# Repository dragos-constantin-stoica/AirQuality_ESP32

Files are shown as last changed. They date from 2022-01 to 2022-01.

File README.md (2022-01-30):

# AirQuality monitoring with ESP32
Air Quality, Temperature, Humidity IoT platform with ESP32

## Introduction

This is a prototype for a station that is monitoring the following parameters:
- Temperature in °C, if you use F please change accordingly in the code
- Humidity in %
- Air Quality in ppm. The sensor measures: CO, Alcohol, CO2, Tolueno, NH4, and Acetona

The device will store the measured data on SD card and is programmed to send data to uBeac, as IoT data collection platform.

The main microcontroller is ESP32 (WROOM-32) and it has the follwing peripherals:
- MQ135 air quality sensor
- DHT22 temperature and humidity sensor
- microSD card reader
- DS3231 RTC clock
- SSD1306 OLED display

Most of the components were purchased from [AZ-Delivery](https://www.az-delivery.de/en) and [Amazon](https://www.amazon.de/)

## What can you find in this repository?

### AQ

Contains the Arduino code. I used Arduino v1.8.19 desktop on a MacBook.
Extra repository configuraiton:
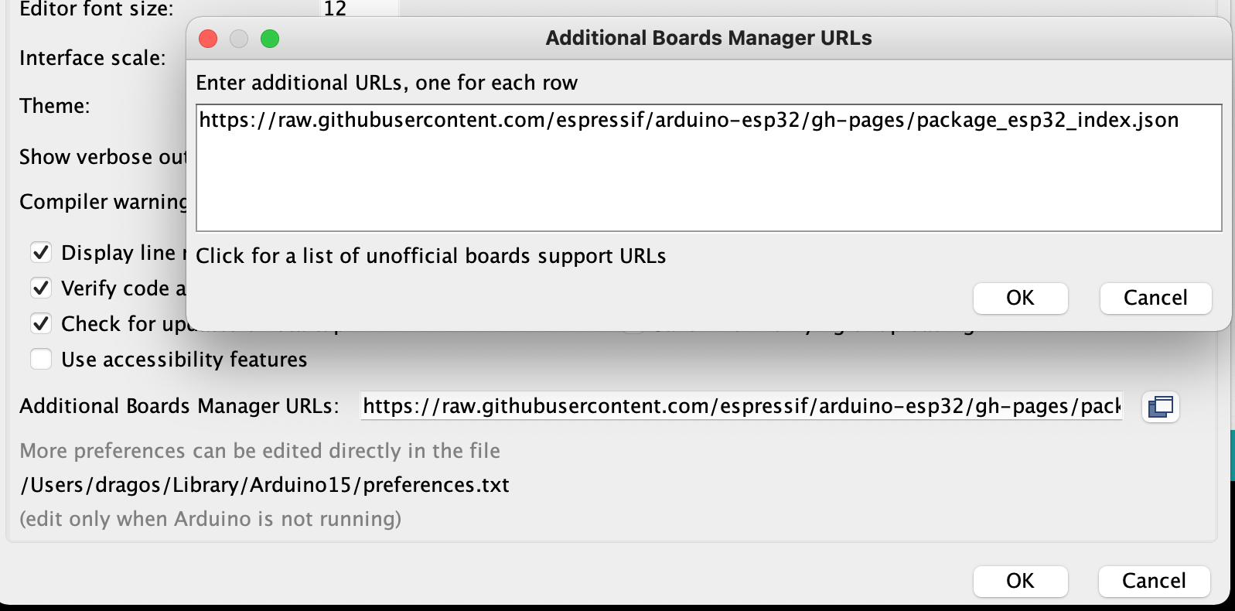
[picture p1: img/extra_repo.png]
Add extra repositories

This is the official repository provided by Expressif - the manufacturer of the ESP32 chipset.

List of libraries:
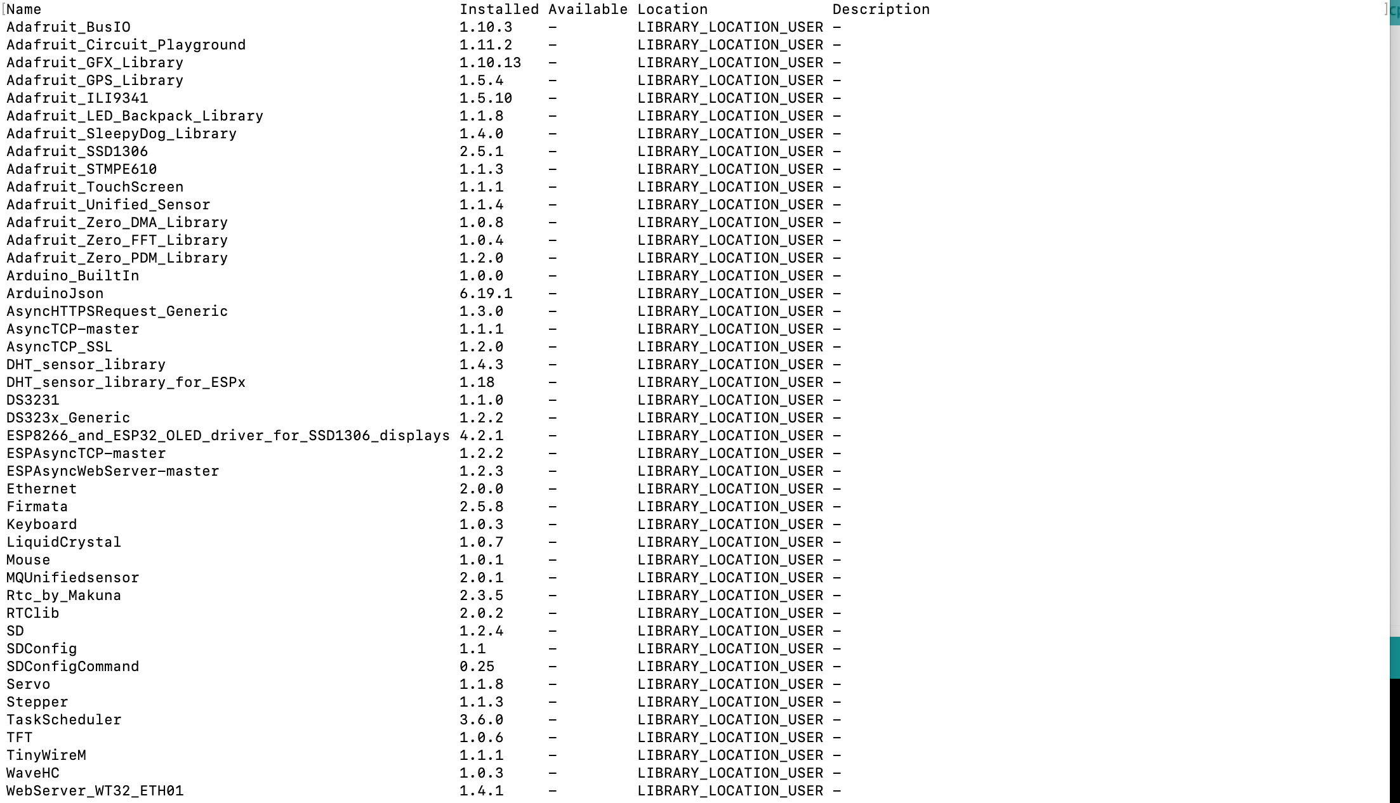
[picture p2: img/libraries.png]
Extra libraries


Some libraries were downloaded and installed manually.

Board configuration:
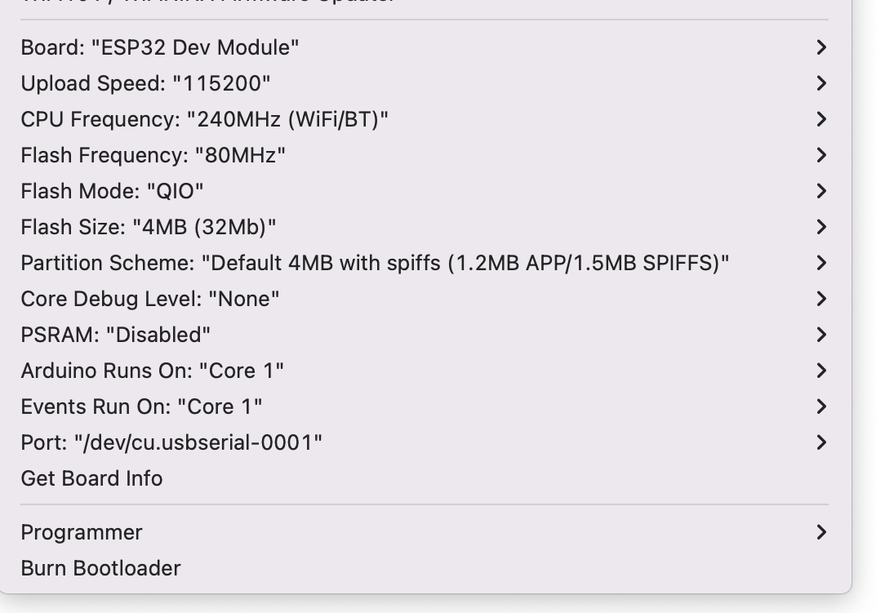
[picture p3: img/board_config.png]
Board configuration


Build the code and upload it into device via USB cable. You need USB to microUSB cable.

### Fritzing

The Fritzing schema. You can find the electronic schema and the breadboard prototype. The PCB was generated by Fritzing but not used for the actual implementation and soldering.

I used an one hole PCB card 7x9 cm for the final soldering of components.

### SD_card

This folder must be copied onto the SD card before you start the Air Quality monitoring station. You have an **index.html** file that will be served by the local web server. The web server is accessible via the IP displayed on OLED.  
The system log file is also stored on the SD card - see file **airquality.log**. This file can be accessed via the local web sever.  

The most important file is the **aq.cfg** this contains the configuration that will initialize the system. You **must** provide an **WiFi SSID** so that the device can connect and start monitoring. Additionally you can send the data to [uBeac](https://ubeac.io). Please follow the instructions on uBeac site in order to create the propper configuration and include it in **aq.cfg**.

## How does it work?
You need to build the physical device before starting. You can either use a breadboard with wires or solder the components on a PCB. I do recommend to start with breadboard first. Use fritzing schema to build the device.

Step 0.   
Format the SD card as fat. I used a 16GB microSD card. The speed of the card is not important.

Step 1.  
Edit aq.cfg file accordingly before copying. Copy the files from forder SD_card to your microSD card. 

Step 2.  
Copile and upload the AQ.ino on ESP32 board.

The device must boot and show a message on OLED that looks like:
```
WiFi SSID [OK]
uBeac setup [OK]
DHT22 [OK]
MQ135 [OK]
AQ monitoring [OK]
IP: 192.168.178.58
```

You can use the serial monitor from Ardunio to see the verbouse log. This is an excellent tool for debugging and troubleshooting.

:four_leaf_clover: Wish you best of luck! :four_leaf_clover:

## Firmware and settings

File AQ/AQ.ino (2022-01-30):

//
//
//  Air Quality (AQ)
//
//  This is a prototype for air quality monitoring system.
//  It runs on an ESP32 platform with
//  - MQ135 sensor for gas
//  - DHT22 sensor for temperature and humidity
//
//  @author: Dragoş STOICA
//  @email: dragos.constantin.stoica@outlook.com
//  @date: 07.09.2020
//

/****************************************
   Include Libraries
 ****************************************/
#include "utilsSD.h"
#include "utilsCfg.h"
#include "utilsTime.h"
#include "utilsOLED.h"
#include "utilsSensor.h"
#include "utilsWiFi.h"


extern bool IS_WIFI;
//-------------------------------------------------------------------------
// Prepare the device:
// - sync time
// - initialize sensors
// - start local webserver
//-------------------------------------------------------------------------
void setup() {
  //init and get the time
  setenv("TZ", "  CET-1CEST,M3.5.0,M10.5.0/3", 1);
  // You must include '0' after first designator e.g. GMT0GMT-1, ',1' is true or ON

  Serial.begin(115200);
  Serial.println("'Oo._");
  Serial.println("*** Program Start : ESP32 with MQ135 and DHT22");
  /*
     The main init sequence

     0. Init SD card
        - read WiFi config from aq.cfg
        - read IoT config form aq.cfg
        - write log file airquality.log
     1. Init OLED
     2. Init Sensors
     3. Init WiFi
        - init Webserver if WiFi config present
        - init IoT send data if IoT config present

     Deal with RTC init
      > initialize RTC first
      > consider that RTC is OK and use it from the beggining
      > when WiFi connection is established do synchronize the RTC with web time server
  */
  init_RTC();
  sd_init();
  cfg_init();
  oled_init();

  // Initialize temperature and air quality sensors
  initDHT22();
  oled_addline("DHT22 [OK]");
  initMQ135();
  oled_addline("MQ135 [OK]");

  if (IS_WIFI) {
    oled_addline("AQ monitoring [OK]");
    wifi_init();
  } else {
    oled_addline("AQ monitoring !NOK!");
    oled_addline(">... SYSTEM HALT!");
    oled_display();
  }
}

void loop() {
  if (IS_WIFI) {
    wifi_run();
  }
}

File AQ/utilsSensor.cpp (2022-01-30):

// Include the necessary libraries
#include "utilsSensor.h"
#include "utilsTime.h"
#include "utilsSD.h"
#include <Arduino.h>


DHT_Unified dht(DHTPIN, DHTTYPE);
MQUnifiedsensor MQ135(Board, Voltage_Resolution, ADC_Bit_Resolution, Pin, Type);
SENSOR_DATA last_reading = { 0.0, 0.0, 0.0, 0.0, 0.0, 0.0, 0.0, 0.0 };


/* Init sensors */
void initDHT22() {
  // Initialize device.
  dht.begin();
  Serial.println(F("DHT22 Unified Sensor"));
  // Print temperature sensor details.
  sensor_t sensor;
  dht.temperature().getSensor(&sensor);
  Serial.println(F("------------------------------------"));
  Serial.println(F("Temperature Sensor"));
  Serial.print  (F("Sensor Type: ")); Serial.println(sensor.name);
  Serial.print  (F("Driver Ver:  ")); Serial.println(sensor.version);
  Serial.print  (F("Unique ID:   ")); Serial.println(sensor.sensor_id);
  Serial.print  (F("Max Value:   ")); Serial.print(sensor.max_value); Serial.println(F("°C"));
  Serial.print  (F("Min Value:   ")); Serial.print(sensor.min_value); Serial.println(F("°C"));
  Serial.print  (F("Resolution:  ")); Serial.print(sensor.resolution); Serial.println(F("°C"));
  Serial.println(F("------------------------------------"));
  // Print humidity sensor details.
  dht.humidity().getSensor(&sensor);
  Serial.println(F("Humidity Sensor"));
  Serial.print  (F("Sensor Type: ")); Serial.println(sensor.name);
  Serial.print  (F("Driver Ver:  ")); Serial.println(sensor.version);
  Serial.print  (F("Unique ID:   ")); Serial.println(sensor.sensor_id);
  Serial.print  (F("Max Value:   ")); Serial.print(sensor.max_value); Serial.println(F("%"));
  Serial.print  (F("Min Value:   ")); Serial.print(sensor.min_value); Serial.println(F("%"));
  Serial.print  (F("Resolution:  ")); Serial.print(sensor.resolution); Serial.println(F("%"));
  Serial.println(F("------------------------------------"));
  // Set delay between sensor readings based on sensor details.
  //delayMS = sensor.min_delay / 1000;
  logSDCard("[SENSOR]","initDHT22: " + String(sensor.name) + " initialization successful");  

};

void initMQ135() {

  //Set math model to calculate the PPM concentration and the value of constants
  MQ135.setRegressionMethod(1); //_PPM =  a*ratio^b

  /*****************************  MQ Init ********************************************/
  //Remarks: Configure the pin of arduino as input.
  /************************************************************************************/
  MQ135.init();
  /*
    //If the RL value is different from 10K please assign your RL value with the following method:
    MQ135.setRL(10);
  */
  /*****************************  MQ CAlibration ********************************************/
  // Explanation:
  // In this routine the sensor will measure the resistance of the sensor supposing before was pre-heated
  // and now is on clean air (Calibration conditions), and it will setup R0 value.
  // We recomend execute this routine only on setup or on the laboratory and save on the eeprom of your arduino
  // This routine not need to execute to every restart, you can load your R0 if you know the value
  // Acknowledgements: https://jayconsystems.com/blog/understanding-a-gas-sensor
  Serial.print("Calibrating MQ135 please wait.");
  float calcR0 = 0;
  for (int i = 1; i <= 10; i ++)
  {
    MQ135.update(); // Update data, the arduino will be read the voltage on the analog pin
    calcR0 += MQ135.calibrate(RatioMQ135CleanAir);
    Serial.print(".");
  }
  MQ135.setR0(calcR0 / 10);
  Serial.println("  done!.");

  if (isinf(calcR0)) {
    Serial.println("Warning: Conection issue founded, R0 is infite (Open circuit detected) please check your wiring and supply");
    logSDCard("[SENSOR]","initMQ135: Warning - Conection issue founded, R0 is infite (Open circuit detected) please check your wiring and supply");  
    while(1);
  }
  if (calcR0 == 0) {
    Serial.println("Warning: Conection issue founded, R0 is zero (Analog pin with short circuit to ground) please check your wiring and supply");
    logSDCard("[SENSOR]","initMQ135: Warning - Conection issue founded, R0 is zero (Analog pin with short circuit to ground) please check your wiring and supply");  
    while(1);
  }
  /*****************************  MQ CAlibration ********************************************/
  Serial.println(F("------------------------------------"));
  logSDCard("[SENSOR]","initMQ135: MQ135 initialization successful");  

};

/* Read data from sensors */
void readDTH22() {
  // Get temperature event and print its value.
  sensors_event_t event;

  Serial.println("*** Readings from DHT-22 ****");
  dht.temperature().getEvent(&event);
  if (isnan(event.temperature)) {
    Serial.println(F("Error reading temperature!"));
    logSDCard("[SENSOR]","readDTH22: ERROR reading temperature!");  
  }
  else {
    Serial.print(F("Temperature: "));
    Serial.print(event.temperature);
    Serial.println(F("°C"));
    last_reading.temperature = event.temperature;
    last_reading.ts = getTimeStamp();
    logSDCard("[SENSOR]","readDTH22: T: " + String(event.temperature) + "C");  
  }

  // Get humidity event and print its value.
  dht.humidity().getEvent(&event);
  if (isnan(event.relative_humidity)) {
    Serial.println(F("Error reading humidity!"));
    logSDCard("[SENSOR]","readDTH22: ERROR reading humidity!");  
  }
  else {
    Serial.print(F("Humidity: "));
    Serial.print(event.relative_humidity);
    Serial.println(F("%"));
    last_reading.humidity = event.relative_humidity;
    last_reading.ts = getTimeStamp();

    logSDCard("[SENSOR]","readDTH22: H2O: " + String(event.relative_humidity) + "%");      
  }
  Serial.println("******************************");

};

float configureMQ135(float A, float B) {
  MQ135.setA(A);
  MQ135.setB(B);
  return MQ135.readSensor();
}
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
